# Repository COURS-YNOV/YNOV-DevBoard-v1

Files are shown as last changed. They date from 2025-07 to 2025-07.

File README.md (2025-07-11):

# 📟 Projet YNOV-DevBoard-v1 – Software & Hardware

Ce dépôt Git regroupe l'ensemble du projet **YNOV-DevBoard v1**, développé dans le cadre des cours de **Conception** & **Validation Électronique** en Master 1 à YNOV Bordeaux Campus.

Il contient deux dossiers complémentaires :

- Un contenant le **logiciel embarqué** permettant la réalisation des tests sur la carte.
- Un contenant le **projet hardware** complet de conception de la carte basée sur l’ESP32-PICO-D4.

---

## 🗂 Structure du dépôt

```
YNOV-DevBoard-v1/
│
├── software/   # Code source embarqué, tests unitaires, tests fonctionnels 
├── hardware/   # Schéma, PCB, documentation et contraintes de conception
└── README.md   # Ce fichier
```

---

## 🧪 Dossier `software/` – Logiciel embarqué de tests

Ce dossier contient le logiciel développé pour tester automatiquement les fonctionnalités de la carte **YNOV-DevBoard v1**.

📌 Fonctionnalités principales :
- Tests des capteurs (INA, TMP126, CTN)
- Tests des interfaces de communication (I2C, SPI, BLE)
- Tests des éléments HMI (LEDs, buzzer)
- Génération de **logs SPIFFS** pour suivre l’état des tests
- Contrôle local ou distant (via **BLE** avec l'application Python [`TheESP32Controller`](https://github.com/COURS-YNOV/TheESP32Controller))

🧪 Outils utilisés :
- PlatformIO + Framework Arduino
- Unity Framework pour les tests unitaires

📂 Pour plus de détails 👉 [Software/README.md](./Software/README.md)

---

## 📟 Dossier `hardware/` – Conception de la carte YNOV-DevBoard v1

Ce dossier contient tous les éléments nécessaires à la conception de la carte électronique :

📌 Spécifications :
- Microcontrôleur **ESP32-PICO-D4**
- Triple source d’alimentation (USB-C, BT, HT jusqu’à 36V)
- Capteurs de courant, tension, température (INA237, CTN, TMP126)
- Interfaces **BLE**, **MikroBus**, **Grove**
- Buzzer, LEDs, boutons BOOT et RESET

🔧 Fichiers fournis :
- Projet **Altium Designer** avec schématique & PCB vierges
- Bibliothèques de composants
- Contraintes de routage strictes (sans composants sur face bottom, pas d’angles droits, plan de masse obligatoire…)

📂 Pour plus de détails 👉 [Hardware/README.md](./Hardware/README.md)

---

## 🎓 Objectifs pédagogiques

- Concevoir une carte électronique respectant des contraintes industrielles.
- Développer un logiciel de test modulaire et automatisé.
- Apprendre les bonnes pratiques de tests embarqués (unitaires, fonctionnels, utilisation de logs ...).
- Travailler en synergie entre le hardware et le software.

---

## 📣 Remarques

- Ce projet est réalisé en **groupe**, mais la **notation est individuelle**.
- Des critères précis de notation sont définis dans chaque dossier (`software` et `hardware`).

---

## 🤝 Encadrement

Pour toute question ou besoin de support :
- Contactez vos **enseignants** :
  - [@Jordan CLÉMENT](https://github.com/Jordan18122000)
  - [@Dorian FOURNIER](https://github.com/DorianFournier)

- Utilisez les issues GitHub ou le canal de communication de votre groupe

---

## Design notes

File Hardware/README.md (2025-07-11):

# 📟 Projet Hardware – Carte de Développement YNOV-DevBoard-v1

## 📌 Objectifs

Vous devez concevoir une **carte électronique à base d’ESP32-PICO-D4** répondant aux exigences suivantes :

- **Alimentation multiple** avec priorité :
  - USB-C (5V)
  - Basse Tension (2.7V – 10V)
  - Haute Tension (jusqu’à 36V)
- **Capteurs**  :
   - Courant et tension via INA (communication en I2C)
   - Température via CTN (ADC)
   - Température via TMP126 (communication en SPI)
- **Interface homme-machine** :
  - Buzzer
  - LEDs
  - Boutons **Boot** et **Reset**
- **ICommunication sans fil** :
  - BLE
- **Compatibilité avec MikroBus et Grove**

### Étapes de réalisation

1. Analyse fonctionnelle du système
2. Sélection des composants
3. Réalisation de la schématique
4. Routage du PCB (taille max : **70mm x 50mm**)
5. Fournir :
   - Fichiers DRC sans erreurs
   - Fichiers de fabrication

Un projet Altium est fourni avec :
- Une schématique vide
- Un PCB vide
- Des bibliothèques de symboles et empreintes

---

## 📊 Notation

| Attendus | Points |
|---|---|
| **Schématique** | |
| Réalisation de la schématique | 7 |
| Câblage correct | 5 |
| Lisibilité de la schématique | 2 |
| **PCB** | |
| Réalisation du PCB | 5 |
| Respect des règles de routage/taille | 2 |
| DRC sans erreur | 2 |
| Fichiers de fabrication | 1 |
| **Rapport** | |
| Analyses fonctionnelles | 2 |
| Explication des blocs schématiques | 2 |
| Problèmes rencontrés + solutions | 2 |
| Suivi projet (jalons) | 2 |

⏳ **Deadline : 16 décembre 2024 à 17h00**  
📁 À rendre dans un `.zip` nommé `Equipe_NumeroX_Projet_rendu`, à **push sur GitHub** :  
👉 https://github.com/COURS-YNOV/Projet-YNOV-DevBoard-v1

---

## 📅 Planning recommandé

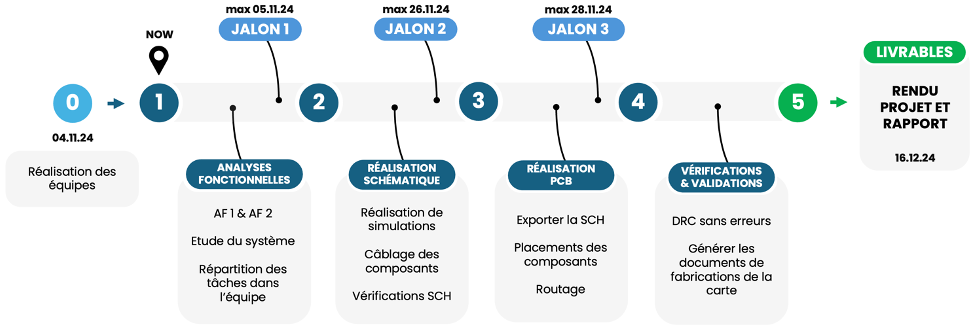
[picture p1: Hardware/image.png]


---

## 🔩 Composants principaux

| Fonction | Référence |
|---|---|
| Microcontrôleur  | ESP32-PICO-D4 |
| USB-UART | CP2104-F03-GM |
| Connecteur USB-C | USB4085-GF-A |
| Capteur courant  | INA237AIDGST |
| Divers | Résistances, Capa, LED, MikroBus, Grove, Antenne, boutons Boot/Reset, etc. |

---

## 🧩 Rappel schéma fonctionnel

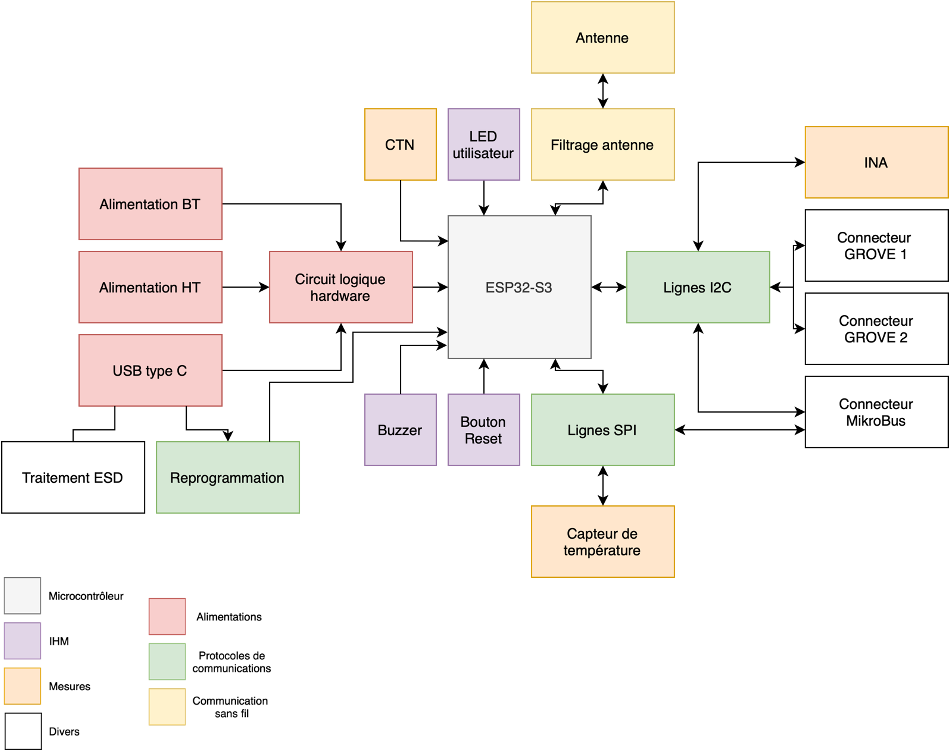
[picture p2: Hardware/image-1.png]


---

## 📐 Règles de conception imposées

### Général

- Schéma en **mils**
- PCB en **mm**
- Titre, révision et nom du dessinateur sur la schématique

### Schématique

- Les **paires différentielles** doivent apparaître

### Routage

- ❌ **Pas d’angles droits**
- ✅ Connexions au **centre des pads**
- ✅ Éviter les angles aigus/soudures complexes
- ✅ Plan de masse **obligatoire**
- ❌ Aucun composant sur la face **Bottom**
- **Vias** :
  - Pad : 0.85 mm
  - Trou : 0.35 mm
- **Sérigraphie** : largeur min. 0.15 mm
- **Impédance ligne de reprogrammation** : 50 Ohms
- **Plan masse/puissance** adapté à l'antenne BLE
- Vias d’assemblage selon besoins (Top layer)

---

## 🔗 Liens utiles

| Description | Lien |
|---|---|
| Raccourcis Altium | [click](https://www.altium.com/documentation/altium-designer/shortcut-keys#shortcut-listings) |
| Guide de routage | [click](https://www.rowsum.com/fr/31-conseils-de-routage-des-circuits-imprimes/) |
| Calculateur de résistance | [click](https://www.digikey.fr/en/resources/conversion-calculators/conversion-calculator-led-series-resistor) |

---

## 💬 Remarque

Ce projet est **en groupe**, mais la **notation est individuelle**.

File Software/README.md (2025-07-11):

# 🧪 Logiciel de Vérification et Validation Électronique – M1 Ynov

Ce dépôt contient le logiciel embarqué utilisé dans le cadre du cours de **Vérification et Validation Électronique** destiné aux étudiants de **Master 1**.  
Le logiciel est développé avec **PlatformIO** et le **framework Arduino**, et doit être déployé sur une carte **ESP32-PICO-D4**.

Ce projet vise à fournir une solution d'automatisation pour effectuer des tests sur des cartes électroniques, permettant ainsi de valider leur bon fonctionnement.

---

## 🎯 Objectif

Le but de ce projet est de permettre aux étudiants de réaliser des **tests automatisés** sur les cartes électroniques **YNOV-DevBoard v1**. Ces tests peuvent être exécutés localement sur la carte ou à distance via l'application Python **TheESP32Controller**, qui interagit avec la carte grâce à la bibliothèque [`bleak`](https://github.com/hbldh/bleak) pour la gestion de la communication Bluetooth Low Energy (BLE).

Les tests automatisés couvrent diverses fonctionnalités matérielles de la carte et permettent de vérifier leur bon fonctionnement avant leur mise en production.

---

## ⚙️ Technologies utilisées

- **ESP32-PICO-D4** : Microcontrôleur présent sur la carte YNOV-DevBoard-v1.
- **PlatformIO** : IDE utilisé pour gérer la compilation, l'upload, et les tests unitaires.
- **Arduino Framework** : Framework de programmation utilisé pour simplifier le développement embarqué.
- **BLE (Bluetooth Low Energy)** : Technologie de communication sans fil pour l'interaction avec l'application Python [`TheESP32Controller`](https://github.com/COURS-YNOV/TheESP32Controller).
- **Bleak** : Bibliothèque utiliséé pour gérer la communication BLE entre la carte et l'application Python "TheESP32Controller".
- **Unity Framework** : Framework de tests unitaires pour vérifier la validité des composants logiciels embarqués.

---

## 🧩 Fonctionnalités & Tests Implémentés

Ce software permet d'exécuter les tests suivants sur la carte **YNOV-DevBoard v1** :

### Tests des périphériques
- 🔴 **Test des LEDs** : Vérifie la bonne activation des LEDs de la carte.
- 🔊 **Test du Buzzer** : Vérifie que le buzzer fonctionne correctement en émettant des sons.
- 🌡️ **Test du capteur de température** : Teste le capteur TMP126 pour s'assurer qu'il peut mesurer la température de manière précise.
- 📉 **Test des CTN (Thermistances)** : Vérifie le bon fonctionnement des capteurs de température thermistances.
- ⚡ **Test du capteur INA** : Vérifie le bon fonctionnement du capteur INA237 pour mesurer la consommation de courant et la tension.
 
### Tests de communication
- 🔗 **Test de la communication I2C** : Vérifie que la communication I2C fonctionne correctement entre l'ESP32 et les périphériques connectés.
- 🔀 **Test de la communication SPI** : Vérifie la communication SPI entre l'ESP32 et les périphériques compatibles SPI (capteur de température).

### Tests de connectivité
- 📡 **Test BLE** : Vérifie la communication Bluetooth Low Energy (BLE) entre l'ESP32 et l'application Python **TheESP32Controller**.

### Tests divers
- **Test PWM** : Vérifie le bon fonctionnement des signaux PWM générés par la carte.
- **Test Free Text** :  Vérifie la bonne reception/envoie de données personnalisées via BLE.
- **Test acknowledge ESP32** : Teste la capacité de la carte ESP32 à répondre à des requêtes de confirmation via BLE.
- 📝 **Test d'écriture/lecture de fichier en RAM** : Vérifie la capacité de l'ESP32 à lire et écrire dans la mémoire RAM pendant l'exécution d'un test.
- 📑 **Test de génération et vérification de logs SPIFFS** : Vérifie l'enregistrement des résultats des tests dans un fichier `log.txt` stocké dans la mémoire SPIFFS de l'ESP32.

---

## ⚙️ Architecture

### Structure du projet
Le projet est organisé en plusieurs dossiers pour une gestion claire et structurée du code source :

- **`src/`** : Contient le code principal de l'application embarquée.
- **`lib/`** : Contient les drivers développés pour la configuration et l'execution des tests.
- **`include/`** : Contient les fichiers constantes et de configurations utilisés dans le projet.
- **`tests/`** : Contient les tests unitaires, organisés par fonctionnalité, pour vérifier le bon fonctionnement du code embarqué.

### 🚀 Téléverser le fichier sur la carte (SPIFFS)

Avant d'exécuter les tests, il est nécessaire de téléverser le fichier `log.txt` dans la mémoire flash SPIFFS de l'ESP32 pour enregistrer les résultats des tests.

Utilisez la commande suivante pour télécharger ce fichier sur l'ESP32 :

```bash
pio run --target uploadfs
```

# 🧪 Tests unitaires embarqués

Des tests unitaires sont inclus dans ce dépôt et peuvent être exécutés à l’aide du framework Unity.

Ces tests permettent de vérifier le bon fonctionnement des différentes parties du code source de manière isolée, garantissant ainsi la fiabilité du firmware.

## ▶️ Lancer les tests unitaires

Pour lancer les tests unitaires sur la plateforme ESP32, utilisez la commande suivante dans PlatformIO :

```bash
pio test -e esp32
```

Cette commande exécute tous les tests définis dans le répertoire `tests/` et génère un rapport détaillant les résultats.

## 📑 Test des logs SPIFFS

Les résultats des tests sont enregistrés dans un fichier `log.txt` situé dans la mémoire flash SPIFFS de l'ESP32. Ce fichier est utilisé pour stocker les résultats de chaque test exécuté. Vous pouvez vérifier son contenu en vous connectant à la carte et en lisant le fichier SPIFFS pour vous assurer que les logs sont correctement enregistrés.

Pour tester cela, vous devez effectuer les étapes suivantes :

1. Exécutez les tests.
2. Vérifiez le fichier `log.txt` dans SPIFFS pour vous assurer que toutes les informations sont correctement enregistrées.
3. Consultez le contenu du fichier avec un logiciel de lecture (par exemple, via un terminal ou en utilisant l'application Python).

## 🧑‍💻 Utilisation du logiciel

### 1. Préparer l'environnement

Clonez le dépôt :

```bash
git clone https://votre-url-de-dépôt.git
```

Installez PlatformIO :

Si vous ne l'avez pas déjà fait, installez PlatformIO en suivant la documentation officielle : PlatformIO.

Installez les dépendances :

Une fois le dépôt cloné, installez les bibliothèques nécessaires à l'aide de la commande suivante :

```bash
pio lib install
```

### 2. Télécharger le firmware sur l'ESP32

Téléversez le firmware sur la carte ESP32 avec la commande suivante :

```bash
pio run --target upload
```

### 3. Exécuter les tests

Les tests peuvent être exécutés de deux manières :

- **Test local** : Exécutez tous les tests unitaires directement sur l'ESP32 :

```bash
pio test -e esp32
```

- **Test via Bluetooth BLE (à distance)** : Utilisez l'application TheESP32Controller en Python pour interagir avec l'ESP32 via BLE et lancer les tests à distance.

### 4. Consulter les logs

Les résultats des tests sont enregistrés dans le fichier `log.txt` dans la mémoire SPIFFS de l'ESP32. Vous pouvez consulter ce fichier pour vérifier l'état de chaque test exécuté.

## 📝 Notation

Voici un tableau de notation qui peut être utilisé pour évaluer la qualité et l'exhaustivité des tests effectués.

| Critère | Description | Points  |
|---|---|---|
| Tests des LEDs | Vérification correcte de l'activation des LEDs. | |
| Test du Buzzer | Vérification correcte du son émis par le buzzer. | |
| Test du capteur TMP126 | Précision des mesures de température. | |
| Tests de communication (I2C, SPI) | Fonctionnalité des communications I2C et SPI. | |
| Test BLE | Bon fonctionnement de la communication BLE. | |
| Tests divers (PWM, Free Text, etc.) | Vérification des autres tests variés. | |
| Test des logs SPIFFS | Enregistrement correct des résultats dans `log.txt`.  | |
| Ajout de tests unitaires | Création de tests unitaires dans le projet.  | |
| Ajout de GitHub Action | Utilisation des GitHub Actions.  | |

## 📋 TODO

Voici une liste des tâches restantes ou des fonctionnalités à ajouter pour améliorer ce projet :

- Tests de la communication avec la ROM externe
- Tests de performance : Implémenter des tests pour mesurer la consommation de mémoire et la performance de l'ESP32 pendant l'exécution des tests.

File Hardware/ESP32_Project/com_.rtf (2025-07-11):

https://www.mouser.fr/datasheet/2/268/MCHP_S_A0010728890_1-2521060.pdf

MCP73831T-3ACI/OT
579-MCP73831T-3ACIOT

https://www.mouser.fr/ProductDetail/Microchip-Technology/MCP73831T-3ACI-OT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

—————————————————————————————————

https://www.digikey.fr/en/products/detail/CP2104-F03-GM/336-2008-5-ND/2486177?curr=usd
CP2104-F03-GM

—————————————————————————————————

https://www.mouser.fr/ProductDetail/AP-Memory/APS1604M-3SQR-SN?qs=IS%252B4QmGtzzpULD7HVv5Qww%3D%3D

PSRAM

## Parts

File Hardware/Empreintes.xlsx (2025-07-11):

NAME | Description | Designator | Qty | MP | Manufacturer | Footprint | V | Check
114020164 | Seeed Studio Accessories Grove Female Header - SMD-4P-2.0mm-90D-20Pcs | J202, J203 | 2 | KO | KO | 114020164 | NA | OK
598-8610-207F | Standard LEDs - SMD Red/Green WC 80/50mcd 645/570nm | D600 | 1 | KO | KO | 5988610207F | NA
0.1uF | Capa | C101, C104, C108, C300, C500 | 5 | KO | KO | CAPA_0603 | NA | OK
0.6pF | Capa | C600 | 1 | KO | KO | CAPA_0603 | NA | OK
0.9pF | Capa | C601 | 1 | KO | KO | CAPA_0603 | NA | OK
1nF | Capa | C105 | 1 | KO | KO | CAPA_0603 | NA | OK
1.0pF | Capa | C602 | 1 | KO | KO | CAPA_0603 | NA | OK
1uF | Capa | C100, C102, C103, C107, C303, C304 | 6 | KO | KO | CAPA_0603 | NA | OK
2.2uF | Capa | C302 | 1 | KO | KO | CAPA_0603 | NA | OK
4.7uF | Capa | C106 | 1 | KO | KO | CAPA_0603 | NA | OK
5mF | Capa | C400 | 1 | KO | KO | CAPA_0603 | NA | OK
10uF | Capa | C301 | 1 | KO | KO | CAPA_0603 | NA | OK
22uF | Capa | C305 | 1 | KO | KO | CAPA_0603 | NA | OK
47nF | Capa | C603, C604, C605, C606 | 4 | KO | KO | CAPA_0603 | NA | OK
100nF | Capa | C200, C401, C402, C403, C404, C405, C406, C407, C501, C502 | 10 | KO | KO | CAPA_0603 | NA | OK
825433-8 | Headers & Wire Housings 8P double for connection mikrobus | J200 | 1 | KO | KO | Connect-Mikrobus | NA
4.7uH | Self | L300 | 1 | KO | KO | LQPC1005X06N | NA
10uF | Capa | L301 | 1 | KO | KO | LQPC1005X06N | NA
NCP167BMX330TBG | Régulateurs de tension LDO LDO 700 MA ULTRA-LOW NOISE 3.3V | U300 | 1 | KO | KO | NCP167BMX330TBG | NA
CP2104-F03-GM | USB Bridge, USB to UART USB 2.0 UART Interface 24-QFN (4x4) | U101 | 1 | KO | KO | PQFN50P400X400X80_HS-25N | NA
ESP32-PICO-D4 | Système RF sur puce - SoC SIP module ESP32 with 4MByte Flash, Dual Core MCU, Wi-Fi & Bluetooth Combo, LGA48-pin, 7*7mm | U100 | 1 | KO | KO | PQFN50P700X700X104_HS-49N | NA
1K | Résistance | R600, R603 | 2 | KO | KO | RES_0603 | NA | OK
2K | Résistance | R502, R503 | 2 | KO | KO | RES_0603 | NA | OK
4.7K | Résistance | R100 | 1 | KO | KO | RES_0603 | NA | OK
5K1 | Résistance | R200, R201 | 2 | KO | KO | RES_0603 | NA | OK
5.1K | Résistance | R605, R607 | 2 | KO | KO | RES_0603 | NA | OK
10K | Résistance | R101, R102, R104, R401, R403, R405, R500, R501, R604, R606 | 10 | KO | KO | RES_0603 | NA | OK
10R | Résistance | R504, R505 | 2 | KO | KO | RES_0603 | NA | OK
22.1K | Résistance | R301 | 1 | KO | KO | RES_0603 | NA | OK
51K | Résistance | R300 | 1 | KO | KO | RES_0603 | NA | OK
100k | Résistance | R302 | 1 | KO | KO | RES_0603 | NA | OK
100K | Résistance | R400, R402, R404 | 3 | KO | KO | RES_0603 | NA | OK
150R | Résistance | R601, R602 | 2 | KO | KO | RES_0603 | NA | OK
510R | Résistance | R103 | 1 | KO | KO | RES_0603 | NA | OK
PSR400ITQFF0L50 | ROHM - PSR400ITQFF0L50 - SMD Current Sense Resistor, 500 ohm, PSR Series, 3921 [1052 Metric], 4 W, +/- 1%, Metal Strip | X500 | 1 | KO | KO | RESC10052X200N | NA
NB12K00103JBB | NTC SMD Thermistor, NB12K, 10K, 5% AVX 10k 0805 Protection NTC Thermistor, 5s, 2 x 1.25 x 1.3mm | B600, B601 | 2 | KO | KO | RESC2212X50N | NA
SD103AWS-7-F | Diode Array 3 Independent Schottky 40V 175mA Surface Mount 6-TSSOP, SC-88, SOT-363 | DARR700, DARR701, DARR702 | 3 | KO | KO | SD103AWS-7-F | NA
IS66WVS1M8BLL-104NLI | SRAM 8Mb, SerialRAM, 2.7V-3.6V, 104MHz, 8 pin SOIC 150 mil, RoHS | U102 | 1 | KO | KO | SOIC127P600X175-8N | NA
INA237AIDGST | Current Sense Amplifiers 85-V, 16-bit, I2C output current/voltage/power monitor with alert 10-VSSOP -40 to 125 | B500 | 1 | KO | KO | SOP50P490X110-10N | NA
TPS62056DGSG4 | TEXAS INSTRUMENTS - TPS62056DGSG4 - Synchronous Buck (Step Down) Switching Regulator, Fixed, 2.7V-10Vin, 3.3V/0.8A out, 850kHz, VSSOP-10 | B301 | 1 | KO | KO | SOP50P490X110-10N | NA
74VHC05FT | Logic Gates CMOS LOGIC IC INVERTER | B401 | 1 | KO | KO | SOP65P640X120-14N | NA
824011 | TVS Diode Array WE-TVS, High Speed Series - Low capazity - No leakage current - Low clamping voltage - high ESD voltage protection -- USB 1.0 - 2.0 | D200 | 1 | KO | KO | SOT23-5 | NA
MC74VHC1GT32DFT1G | Single 2-Input OR Gate, TTL Level | B400, B402, B403 | 3 | KO | KO | SOT65P210X110-5N | NA
TMP126DCKR | Board Mount Temperature Sensors +/-0.25 C SPI temperature sensor with 175 C operation, CRC and slew-rate alert | B501 | 1 | KO | KO | SOT65P210X110-6N | NA
FDV304P | ON SEMICONDUCTOR - FDV304P - Power MOSFET, P Channel, 25 V, 460 mA, 1.22 ohm, SOT-23, Surface Mount | Q400, Q401, Q402 | 3 | KO | KO | SOT95P251X112-3N | NA
LMR50410Y3FQDBVRQ1 | Régulateurs de tension de commutation Automotive qualified SIMPLE SWITCHER 4-V to 36-V, 1-A synchronous step-down converter 6-SOT-23 -40 to 150 | B300 | 1 | KO | KO | SOT95P280X145-6N | NA
2N7002KT1G | MOSFET N-Ch 60V 380mA Small Signal SOT23 ON Semiconductor 2N7002KT1G N-channel MOSFET Transistor, 380 mA, 60 V, 3-Pin SOT-23 | Q600 | 1 | KO | KO | SOT96P237X111-3N | NA
PKLCS1212E40A1-R1 | Buzzers Transducer, Externally Driven Piezo 1.5V 2kHz 70dB @ 1.5V, 10cm Surface Mount Solder Pads | LS600 | 1 | PKLCS1212E40A1-R1 | KO | SPKR_PKLCS1212E40A1-R1 | NA
SS8050-G | Bipolar Transistors - BJT NPN TRANSISTOR 1.5A 40V | Q100, Q101 | 2 | KO | KO | SS8050-G | NA
FSMSM | FSMSM Push Button Switch, 50 mA, -35 to 85 degC, 2-Pin SMD, RoHS, Bulk | SW200, SW201 | 2 | KO | TE Connectivity | TECO-FSMSM-2_V | 24V
Connecteur USB | Connecteurs USB USB Type C, 2.0, Rec, TH , G/F, RA , Top Mnt, T & R | J201 | 1 | KO | KO | USB4085-GF-A | NA
Filtre en mode commun | Bobines / filtres en mode commun WE-CNSW 1206 370mA 90Ohm 100MHz AECQ200 | L200 | 1 | KO | KO | WE-CNSW-1206 | NA
NN03-320 | Dual port antenna booster for GNSS, Bluetooth, 5G and UWB (1561 - 1606MHz, 2400 - 2500MHz, 3400 - 3800MHz, 3100 - 4800MHz and 6000 - 10600 MHz), signal booster | E600 | 1 | KO | KO | XCVR_NN03-320 | NA

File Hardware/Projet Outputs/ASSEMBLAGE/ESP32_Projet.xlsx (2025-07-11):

Comment | Description | Designator | Footprint | LibRef | Quantity | Lien
LMR50410Y3FQDBVRQ1 | Régulateurs de tension de commutation Automotive qualified SIMPLE SWITCHER 4-V to 36-V, 1-A synchronous step-down converter 6-SOT-23 -40 to 150 | B300 | SOT95P280X145-6N | LMR50410Y3FQDBVRQ1 | 1 | https://www.mouser.fr/ProductDetail/Texas-Instruments/LMR50410Y3FQDBVRQ1?qs=81r%252BiQLm7BTaIXwCgdOuiA%3D%3D
TPS62056DGSG4 | TEXAS INSTRUMENTS - TPS62056DGSG4 - Synchronous Buck (Step Down) Switching Regulator, Fixed, 2.7V-10Vin, 3.3V/0.8A out, 850kHz, VSSOP-10 | B301 | SOP50P490X110-10N | TPS62056DGSG4 | 1 | https://www.mouser.fr/ProductDetail/Texas-Instruments/TPS62056DGSG4?qs=Gse6rAGbi7%2FzZ8O9jVxOPw%3D%3D
MC74VHC1GT32DFT1G | Single 2-Input OR Gate, TTL Level | B400, B402, B403 | SOT65P210X110-5N | MC74VHC1GT32DFT1G | 3 | https://www.mouser.fr/ProductDetail/onsemi/MC74VHC1GT32DFT1G?qs=3Rah4i%252BhyCF0HPzZACsD%252BA%3D%3D
74VHC05FT | Logic Gates CMOS LOGIC IC INVERTER | B401 | SOP65P640X120-14N | 74VHC05FT | 1 | https://www.mouser.fr/ProductDetail/Toshiba/74VHC05FT?qs=vPP9GyyTAo2HsJPKD%2FomJQ%3D%3D
INA237AIDGST | Current Sense Amplifiers 85-V, 16-bit, I2C output current/voltage/power monitor with alert 10-VSSOP -40 to 125 | B500 | SOP50P490X110-10N | INA237AIDGST | 1 | https://www.mouser.fr/ProductDetail/Texas-Instruments/INA237AIDGST?qs=CiayqK2gdcJbJJ4nef%252BF8w%3D%3D
TMP126DCKR | Board Mount Temperature Sensors +/-0.25 C SPI temperature sensor with 175 C operation, CRC and slew-rate alert | B501 | SOT65P210X110-6N | TMP126DCKR | 1 | https://www.mouser.fr/ProductDetail/Texas-Instruments/TMP126DCKR?qs=4ASt3YYao0X%252BRzld6Zs7yw%3D%3D
NB12K00103JBB | NTC SMD Thermistor, NB12K, 10K, 5% AVX 10k 0805 Protection NTC Thermistor, 5s, 2 x 1.25 x 1.3mm | B600, B601 | RESC2212X50N | NB12K00103JBB | 2 | https://www.mouser.fr/ProductDetail/KYOCERA-AVX/NB12K00103JBB?qs=4%252B6%252BTdINQeDPvI%252BQUQjJ3Q%3D%3D
1uF |  | C100, C102, C103, C107, C303, C304 | CAPA_0603 | Capacitor | 6 | https://www.mouser.fr/ProductDetail/KYOCERA-AVX/06035C105MAT2A
0.1uF |  | C101, C104, C108, C300, C500 | CAPA_0603 | Capacitor | 5 | https://www.mouser.fr/ProductDetail/TAIYO-YUDEN/MAJCU168BB7104KTEA01?qs=ZcfC38r4PovJ4zMRJqa98Q%3D%3D
1nF |  | C105 | CAPA_0603 | Capacitor | 1 | https://www.mouser.fr/ProductDetail/Murata-Electronics/GRM188R72E102KW07D?qs=0EDxBdtd5TTqBbAL3ZuZjw%3D%3D
4.7uF |  | C106 | CAPA_0603 | Capacitor | 1 | https://www.mouser.fr/ProductDetail/TAIYO-YUDEN/MCASJ168BD7475KTCA01?qs=jcD%2FCkGBYeN5KiSgETBBHQ%3D%3D
100nF |  | C200, C401, C402, C403, C404, C405, C406, C407, C501, C502 | CAPA_0603 | Capacitor | 10 | https://www.mouser.fr/ProductDetail/TAIYO-YUDEN/MAJCU168BB7104KTEA01?qs=ZcfC38r4PovJ4zMRJqa98Q%3D%3D
10uF |  | C301 | CAPA_0603 | Capacitor | 1 | https://www.mouser.fr/ProductDetail/Murata-Electronics/ZRB18AR6YA106ME01L?qs=HoCaDK9Nz5eXg14MFgF2fw%3D%3D
2.2uF |  | C302 | CAPA_0603 | Capacitor | 1 | https://www.mouser.fr/ProductDetail/Samsung-Electro-Mechanics/CL10Y225KA8NRWC?qs=i8QVZAFTkqS9y8P4YmSrrQ%3D%3D
22uF |  | C305 | CAPA_0603 | Capacitor | 1 | https://www.mouser.fr/ProductDetail/KYOCERA-AVX/CM105X5R226M16AT?qs=MyNHzdoqoQKX6cMyStcF%2FA%3D%3D
5mF |  | C400 | CAPA_0603 | Capacitor | 1 | NOT USE
0.6pF |  | C600 | CAPA_0603 | Capacitor | 1 | https://www.mouser.fr/ProductDetail/Murata-Electronics/GRM1885C1HR60WA01D?qs=4W3PNmGdEWEpP9oqudN2kA%3D%3D
0.9pF |  | C601 | CAPA_0603 | Capacitor | 1 | https://www.mouser.fr/ProductDetail/Vishay-Vitramon/VJ0603D0R9VXCQJHT?qs=81r%252BiQLm7BQRNGxx7uvesg%3D%3D
1.0pF |  | C602 | CAPA_0603 | Capacitor | 1 | https://www.mouser.fr/ProductDetail/Vishay-Vitramon/VJ0603D1R0BXPAJ?qs=f%252BL2SN1Gfcun1bEHWO%2FG%252Bw%3D%3D
47nF |  | C603, C604, C605, C606 | CAPA_0603 | Capacitor | 4 | https://www.mouser.fr/ProductDetail/KYOCERA-AVX/KAM15AR71H473KM?qs=Jm2GQyTW%2Fbirhk%2FTN5CLyw%3D%3D
824011 | TVS Diode Array WE-TVS, High Speed Series - Low capazity - No leakage current - Low clamping voltage - high ESD voltage protection -- USB 1.0 - 2.0 | D200 | SOT23-5 | 824011 | 1 | https://www.mouser.fr/ProductDetail/Wurth-Elektronik/824011?qs=Wn16VcyqZWrHR48Vn%2FB8%252Bg%3D%3D
598-8610-207F | Standard LEDs - SMD Red/Green WC 80/50mcd 645/570nm | D600 | 5988610207F | 598-8610-207F | 1 | https://www.mouser.fr/ProductDetail/Dialight/598-8610-207F?qs=7JStj%2FjQ2SFuCjosqwklHQ%3D%3D
SD103AWS-7-F | Diode Array 3 Independent Schottky 40V 175mA Surface Mount 6-TSSOP, SC-88, SOT-363 | DARR700, DARR701, DARR702 | SD103AWS-7-F | SD103AWS-7-F | 3 | https://www.mouser.fr/ProductDetail/Diodes-Incorporated/SD103AWS-7-F?qs=yDXQ%2Fb33kn1tCz%252Bb09bzhg%3D%3D
NN03-320 | Dual port antenna booster for GNSS, Bluetooth, 5G and UWB (1561 - 1606MHz, 2400 - 2500MHz, 3400 - 3800MHz, 3100 - 4800MHz and 6000 - 10600 MHz), signal booster | E600 | XCVR_NN03-320 | NN03-320 | 1 | https://www.mouser.fr/ProductDetail/Ignion/NN03-320?qs=OTrKUuiFdkbF20ahZYIa2w%3D%3D
825433-8 | Headers & Wire Housings 8P double for connection mikrobus | J200 | Connect-Mikrobus | Connect-Mikrobus | 1
Connecteur USB | Connecteurs USB USB Type C, 2.0, Rec, TH , G/F, RA , Top Mnt, T & R | J201 | USB4085-GF-A | USB4085-GF-A | 1 | https://www.mouser.fr/ProductDetail/GCT/USB4085-GF-A?qs=KUoIvG%2F9Ilba1bQOahfWjw%3D%3D
114020164 | Seeed Studio Accessories Grove Female Header - SMD-4P-2.0mm-90D-20Pcs | J202, J203 | 114020164 | 114020164 | 2 | https://www.mouser.fr/ProductDetail/Seeed-Studio/114020164?qs=7MVldsJ5Uayw%2FOfizq4F8w%3D%3D
3.3uH, 3.5A | WE-LHMI SMT Power Inductor, size 4020, 3.3uH, 3.5A, 76mOhm | L1 | WE-LHMI_4020 | 74437324033 | 1 | https://www.mouser.fr/ProductDetail/Wurth-Elektronik/74437324033?qs=cFlH0mFHHFqAbArPxGVEdA%3D%3D
10uH, 2A | WE-PD SMT Power Inductor, size 7345, 10uH, 2A, 49mOhm | L2 | WE-PD_7345 | 74477710 | 1 | https://www.mouser.fr/ProductDetail/Wurth-Elektronik/74477710?qs=E%2F%2FhvbtCqpNuU6Mc9NsODA%3D%3D
Filtre en mode commun | Bobines / filtres en mode commun WE-CNSW 1206 370mA 90Ohm 100MHz AECQ200 | L200 | WE-CNSW-1206 | 744232090 | 1 | https://www.mouser.fr/ProductDetail/Wurth-Elektronik/744232090?qs=PGXP4M47uW6L5fAiLO6yTw%3D%3D
PKLCS1212E40A1-R1 | Buzzers Transducer, Externally Driven Piezo 1.5V 2kHz 70dB @ 1.5V, 10cm Surface Mount Solder Pads | LS1 | SPKR_PKLCS1212E40A1-R1 | PKLCS1212E40A1-R1 | 1 | https://www.mouser.fr/ProductDetail/Murata-Electronics/PKLCS1212E40A1-R1?qs=5UjbJB5E4AfH47ysIIPj%2FQ%3D%3D
SS8050-G | Bipolar Transistors - BJT NPN TRANSISTOR 1.5A 40V | Q100, Q101 | SS8050-G | SS8050-G | 2 | https://www.mouser.fr/ProductDetail/Comchip-Technology/SS8050-G?qs=LLUE9lz1YbcHg%252BWLMAtcrQ%3D%3D
FDV304P | ON SEMICONDUCTOR - FDV304P - Power MOSFET, P Channel, 25 V, 460 mA, 1.22 ohm, SOT-23, Surface Mount | Q400, Q401, Q402 | SOT95P251X112-3N | FDV304P | 3 | https://www.mouser.fr/ProductDetail/onsemi-Fairchild/FDV304P?qs=FOlmdCx%252BAA1BAlCQZu888w%3D%3D
2N7002KT1G | MOSFET N-Ch 60V 380mA Small Signal SOT23 ON Semiconductor 2N7002KT1G N-channel MOSFET Transistor, 380 mA, 60 V, 3-Pin SOT-23 | Q600 | SOT96P237X111-3N | 2N7002KT1G | 1 | https://www.mouser.fr/ProductDetail/onsemi/2N7002KT1G?qs=Jh7l0IbPjifUiTytu%252BGGDQ%3D%3D
4.7K |  | R100 | RES_0603 | Resistor | 1 | https://www.mouser.fr/ProductDetail/KOA-Speer/RS73G1JRTTD4701F
10K |  | R101, R102, R104, R401, R403, R405, R500, R501, R604, R606 | RES_0603 | Resistor | 10 | https://www.mouser.fr/ProductDetail/SEI-Stackpole/RNCE0603BTE10K0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
510R |  | R103 | RES_0603 | Resistor | 1 | https://www.mouser.fr/ProductDetail/ROHM-Semiconductor/KTR03EZPF5100
5K1 |  | R200, R201 | RES_0603 | Resistor | 2 | https://www.mouser.fr/ProductDetail/Vishay/CRCW06035K10FKEC
51K |  | R300 | RES_0603 | Resistor | 1 | https://www.mouser.fr/ProductDetail/Panasonic/ERA-3ARB513V?qs=sGAEpiMZZMtlubZbdhIBIJiMSTY83nT4HuGl7M9CVy4%3D
22.1K |  | R301 | RES_0603 | Resistor | 1 | https://www.mouser.fr/ProductDetail/TE-Connectivity-Holsworthy/RA73F1J22K1BTDF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
100k |  | R302, R400, R402, R404 | RES_0603 | Resistor | 4 | https://www.mouser.fr/ProductDetail/Vishay/CRCW0603100KFKEE
2K |  | R502, R503 | RES_0603 | Resistor | 2 | https://www.mouser.fr/ProductDetail/SEI-Stackpole/RNCE0603BTE2K00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
10R |  | R504, R505 | RES_0603 | Resistor | 2 | https://www.mouser.fr/ProductDetail/SEI-Stackpole/RNCE0603BTE10R0
1K |  | R600, R603 | RES_0603 | Resistor | 2 | https://www.mouser.fr/ProductDetail/SEI-Stackpole/RNCE0603BTE1K00
150R |  | R601, R602 | RES_0603 | Resistor | 2 | https://www.mouser.fr/ProductDetail/SEI-Stackpole/RNCE0603BTE150R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
5.1K |  | R605, R607 | RES_0603 | Resistor | 2 | https://www.mouser.fr/ProductDetail/Vishay/CRCW06035K10FKEC
FSMSM | FSMSM Push Button Switch, 50 mA, -35 to 85 degC, 2-Pin SMD, RoHS, Bulk | SW200, SW201 | TECO-FSMSM-2_V | CMP-2000-07511-1 | 2 | https://www.mouser.fr/ProductDetail/TE-Connectivity-Alcoswitch/FSMSM?qs=UhRTNahLC3yPLf3YjzjKAA%3D%3D
ESP32-PICO-D4 | Système RF sur puce - SoC SIP module ESP32 with 4MByte Flash, Dual Core MCU, Wi-Fi & Bluetooth Combo, LGA48-pin, 7*7mm | U100 | PQFN50P700X700X104_HS-49N | ESP32 | 1 | https://www.mouser.fr/ProductDetail/Espressif-Systems/ESP32-PICO-D4?qs=MLItCLRbWsw7MJlbN3HfdA%3D%3D
CP2104-F03-GM | USB Bridge, USB to UART USB 2.0 UART Interface 24-QFN (4x4) | U101 | PQFN50P400X400X80_HS-25N | USBBridge | 1 | https://www.mouser.fr/ProductDetail/Silicon-Labs/CP2104-F03-GM?qs=j12q4iUN960zrcKDk%2FjKbw%3D%3D
IS66WVS1M8BLL-104NLI | SRAM 8Mb, SerialRAM, 2.7V-3.6V, 104MHz, 8 pin SOIC 150 mil, RoHS | U102 | SOIC127P600X175-8N | SRAM | 1 | https://www.mouser.fr/ProductDetail/ISSI/IS66WVS1M8BLL-104NLI?qs=doiCPypUmgGxZh5L3cgVoQ%3D%3D
NCP167BMX330TBG | Régulateurs de tension LDO LDO 700 MA ULTRA-LOW NOISE 3.3V | U300 | NCP167BMX330TBG | NCP167BMX330TBG | 1 | https://www.mouser.fr/ProductDetail/onsemi/NCP167BMX330TBG?qs=MLItCLRbWsxdhppZpZlnwg%3D%3D
PSR400ITQFF0L50 | ROHM - PSR400ITQFF0L50 - SMD Current Sense Resistor, 500 ohm, PSR Series, 3921 [1052 Metric], 4 W, +/- 1%, Metal Strip | X500 | RESC10052X200N | PSR400ITQFF0L50 | 1 | https://www.mouser.fr/ProductDetail/ROHM-Semiconductor/PSR400ITQFF0L50?qs=493kPxzlxfLaT1w5Mo%252BtHg%3D%3D

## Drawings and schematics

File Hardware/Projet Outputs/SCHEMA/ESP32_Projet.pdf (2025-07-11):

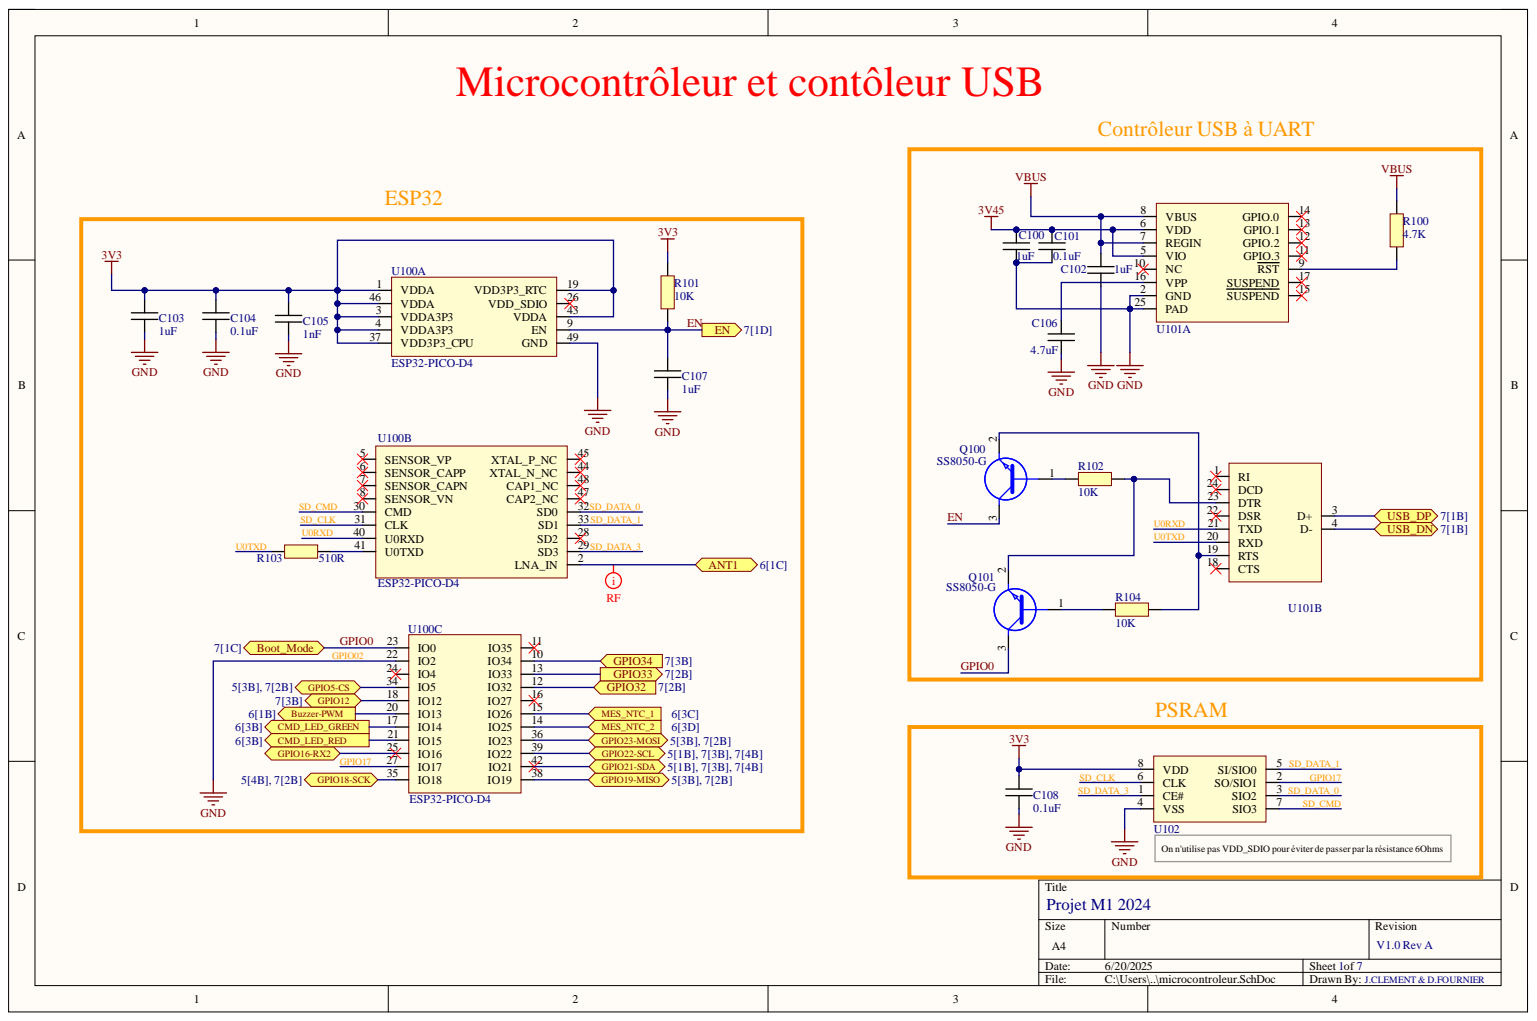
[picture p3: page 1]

4 | 6 | V D D A V D D _SD I O V D D A 3 P 3 V D D A V D D A 3 P 3 E N V D D 3P3 _ C PU G N D | 2 6 3

2 3 5[3B], 7[2B] GP IO5-C S 1 7[3 B ] GP IO1 2 2 6[1 B ] Buz z e r -PWM 1 6[3 B ] C MD_L ED_GR EEN 2 6[3 B ] C MD_L ED_R ED 2 GP IO16-R X 2 | 4 | 13 2 IO33

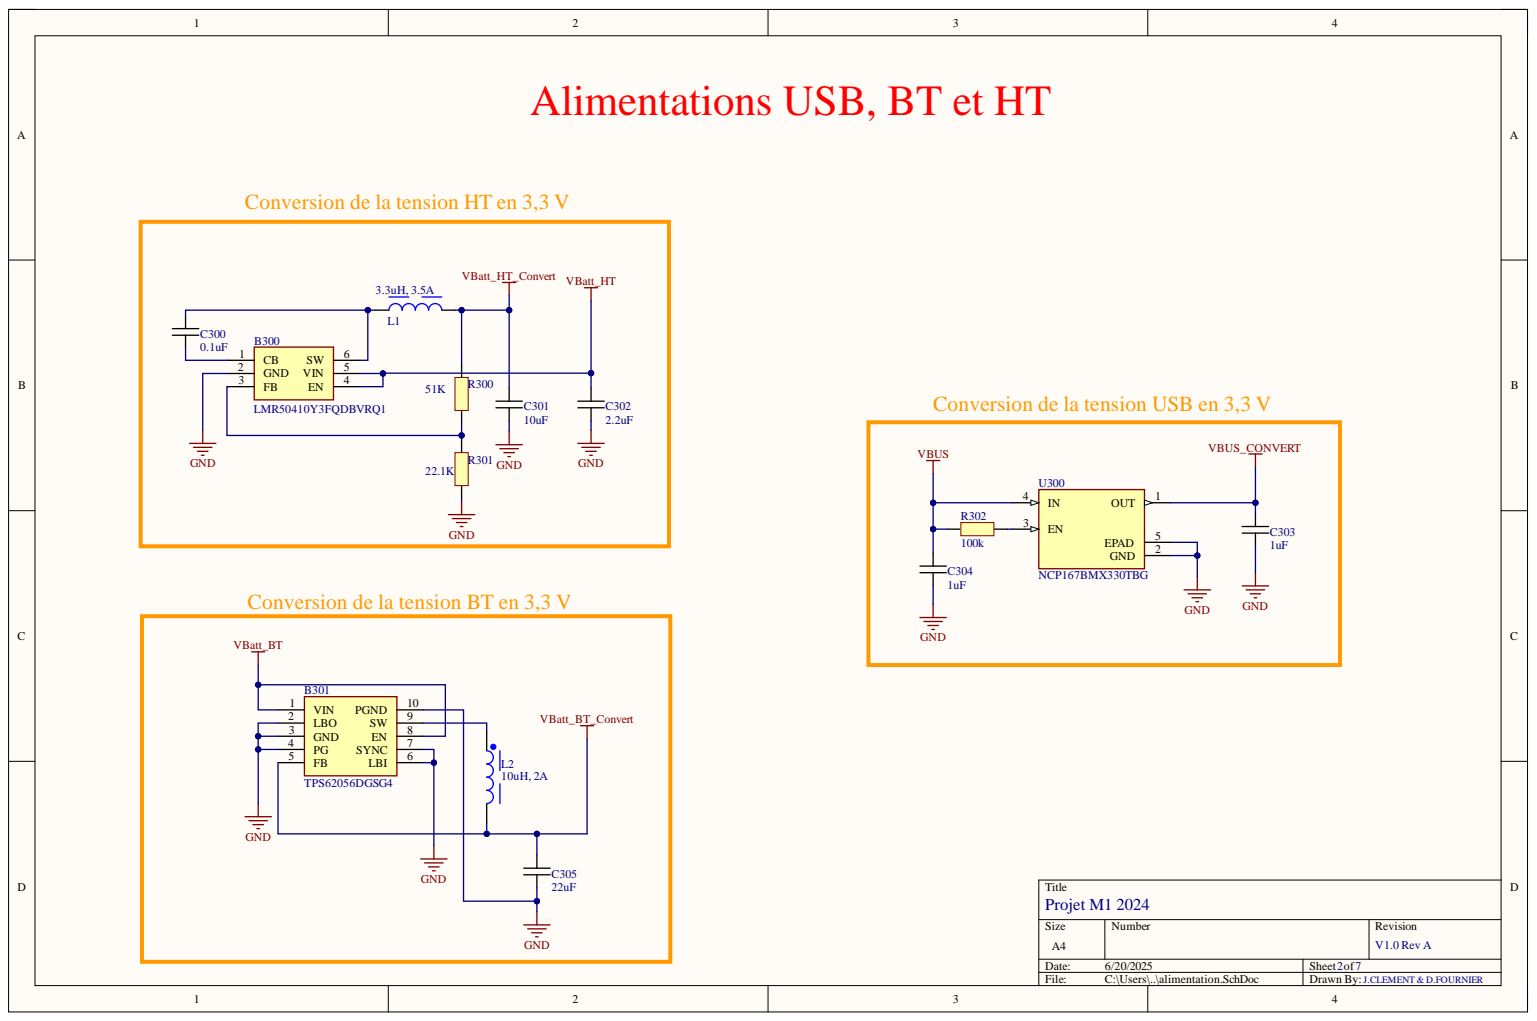
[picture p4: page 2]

Alimentations USB, BT et HT VBatt_HT

3 | | 4 | R3 0 0
FB E N

FB LBI | | 1 0 u H, | 2 A

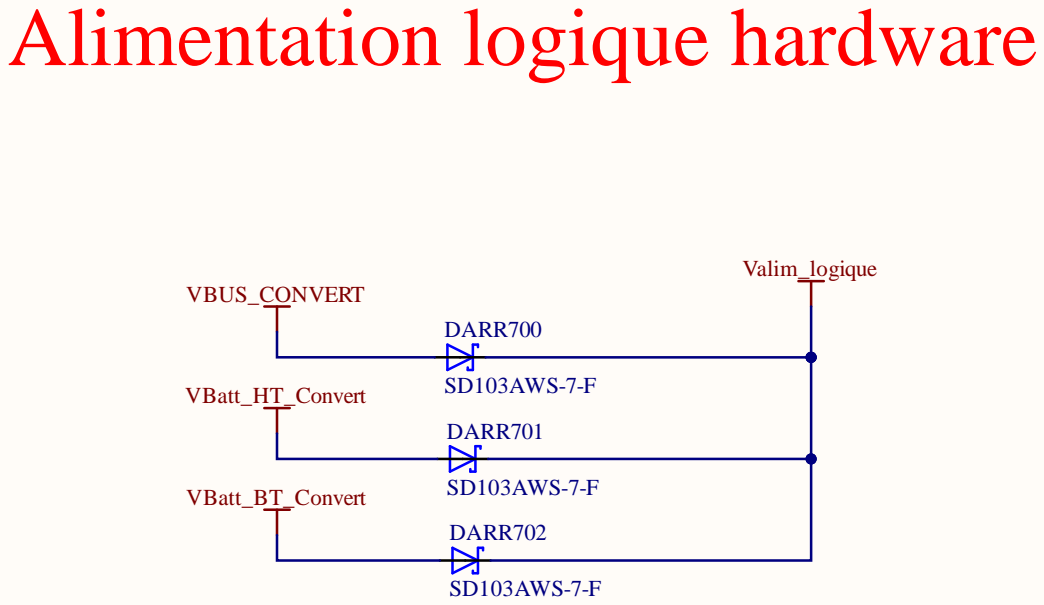
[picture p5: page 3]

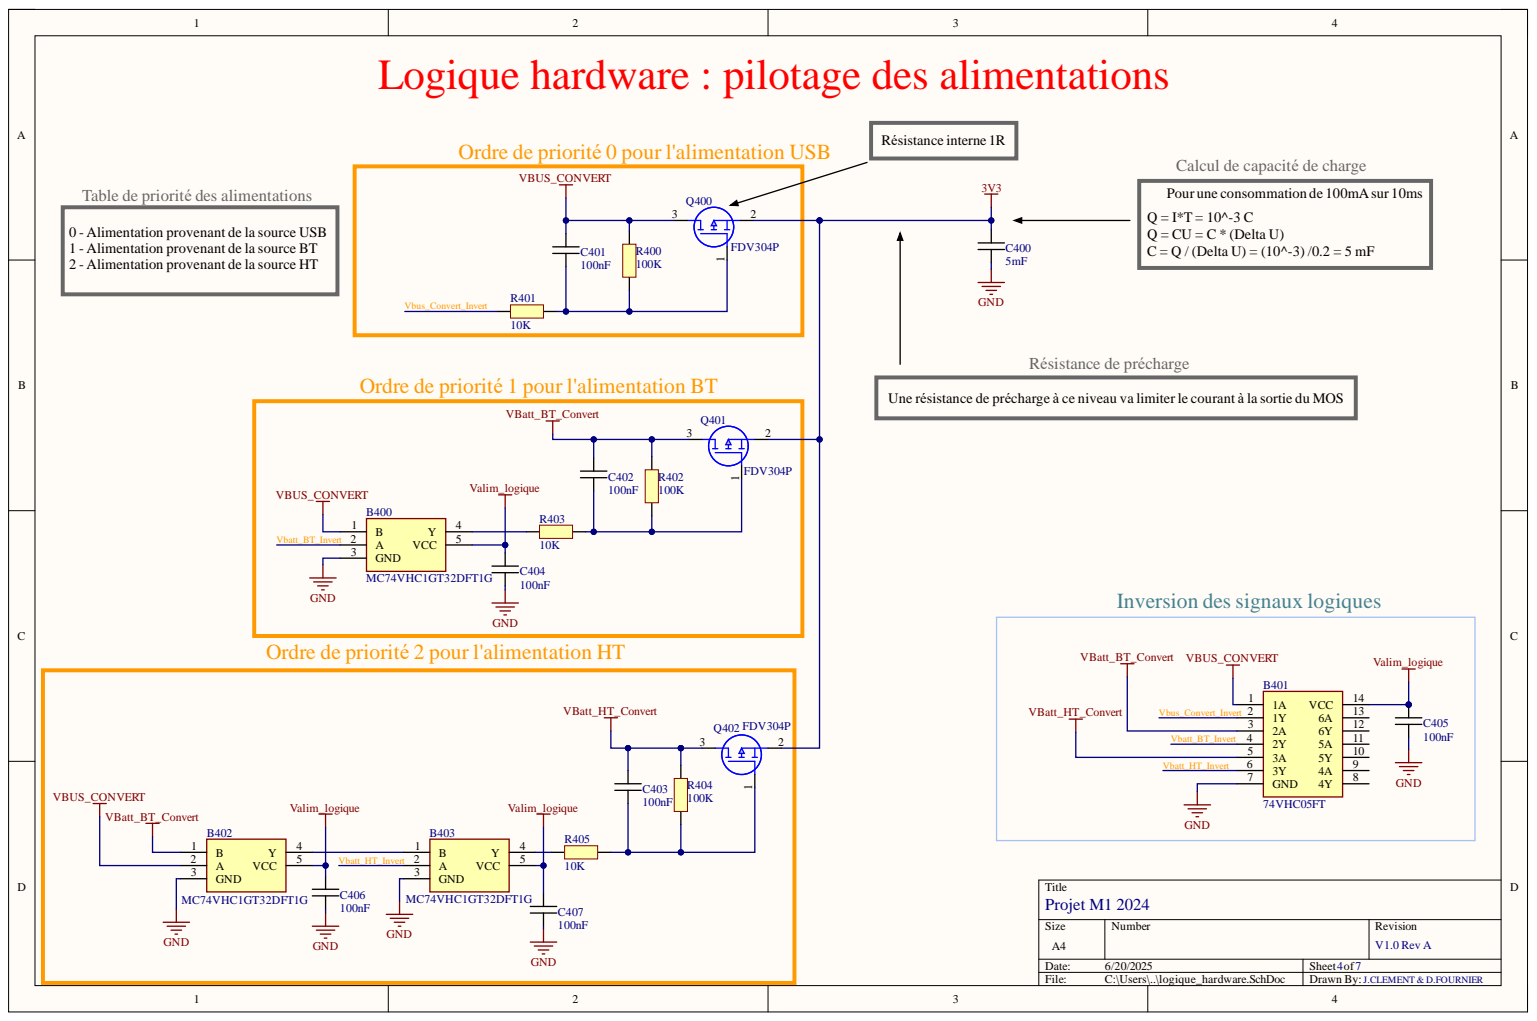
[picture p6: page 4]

Logique hardware : pilotage des alimentations

Ordre de priorité 0 pour l'alimentation USB

Calcul de capacité de charge

Table de priorité des alimentations

Pour une consommation de 100mAsur 10ms
Q = CU = C * (Delta U)
C = Q / (Delta U) = (10^-3) /0.2 = 5 mF

0 - Alimentation provenant de la source USB
1 - Alimentation provenant de la source BT
2 - Alimentation provenant de la source HT

Ordre de priorité 1 pour l'alimentation BT

Une résistance de précharge à ce niveau va limiter le courant à la sortie du MOS

Ordre de priorité 2 pour l'alimentation HT

A 2 | Vbatt_HT_Invert | A 2
GND 3 | | GND 3

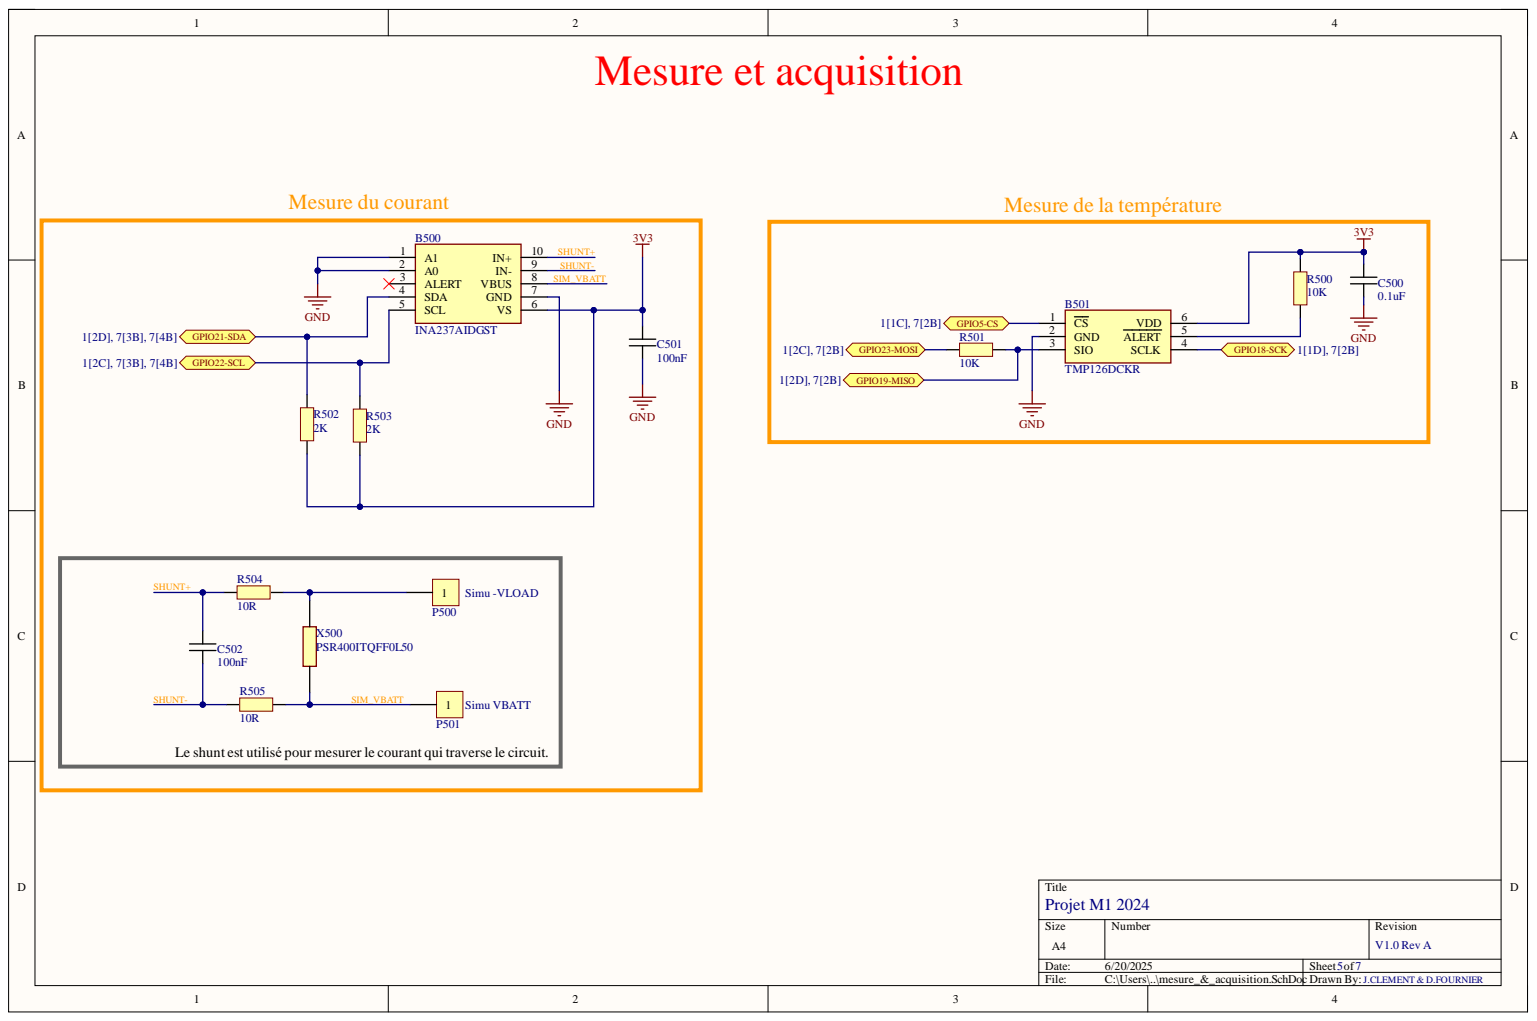
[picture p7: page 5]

2 | 9 | SHUNT -ATT
3 | | 8 7 | S I M_VB

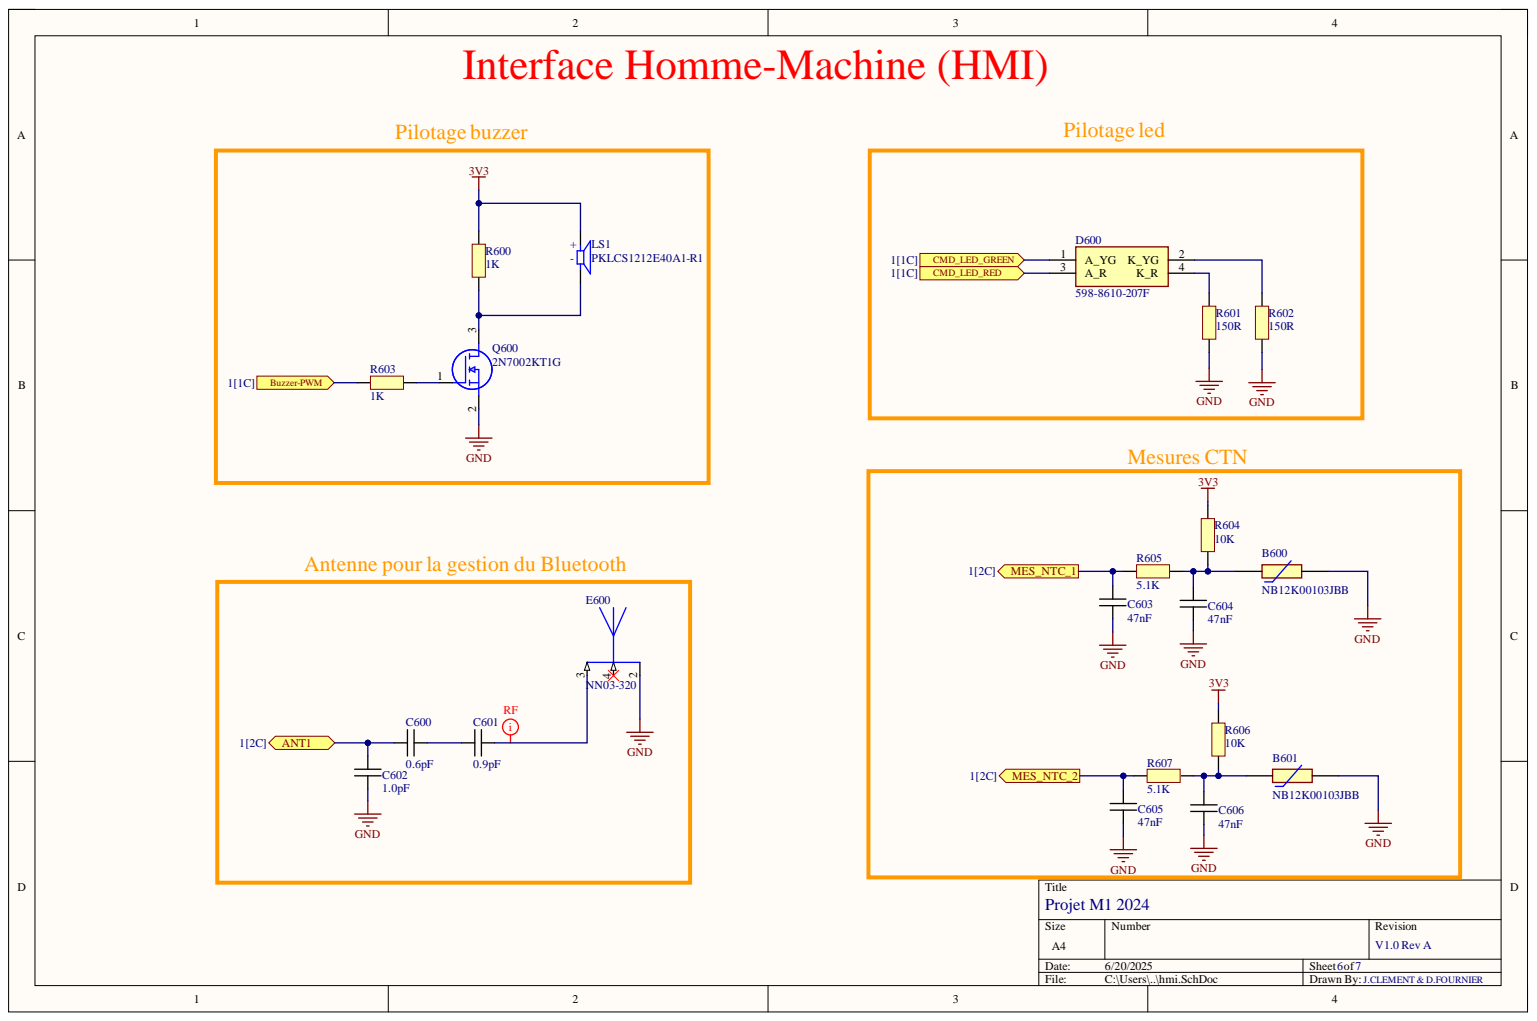
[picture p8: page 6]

Interface Homme-Machine (HMI)

Antenne pour la gestion du Bluetooth

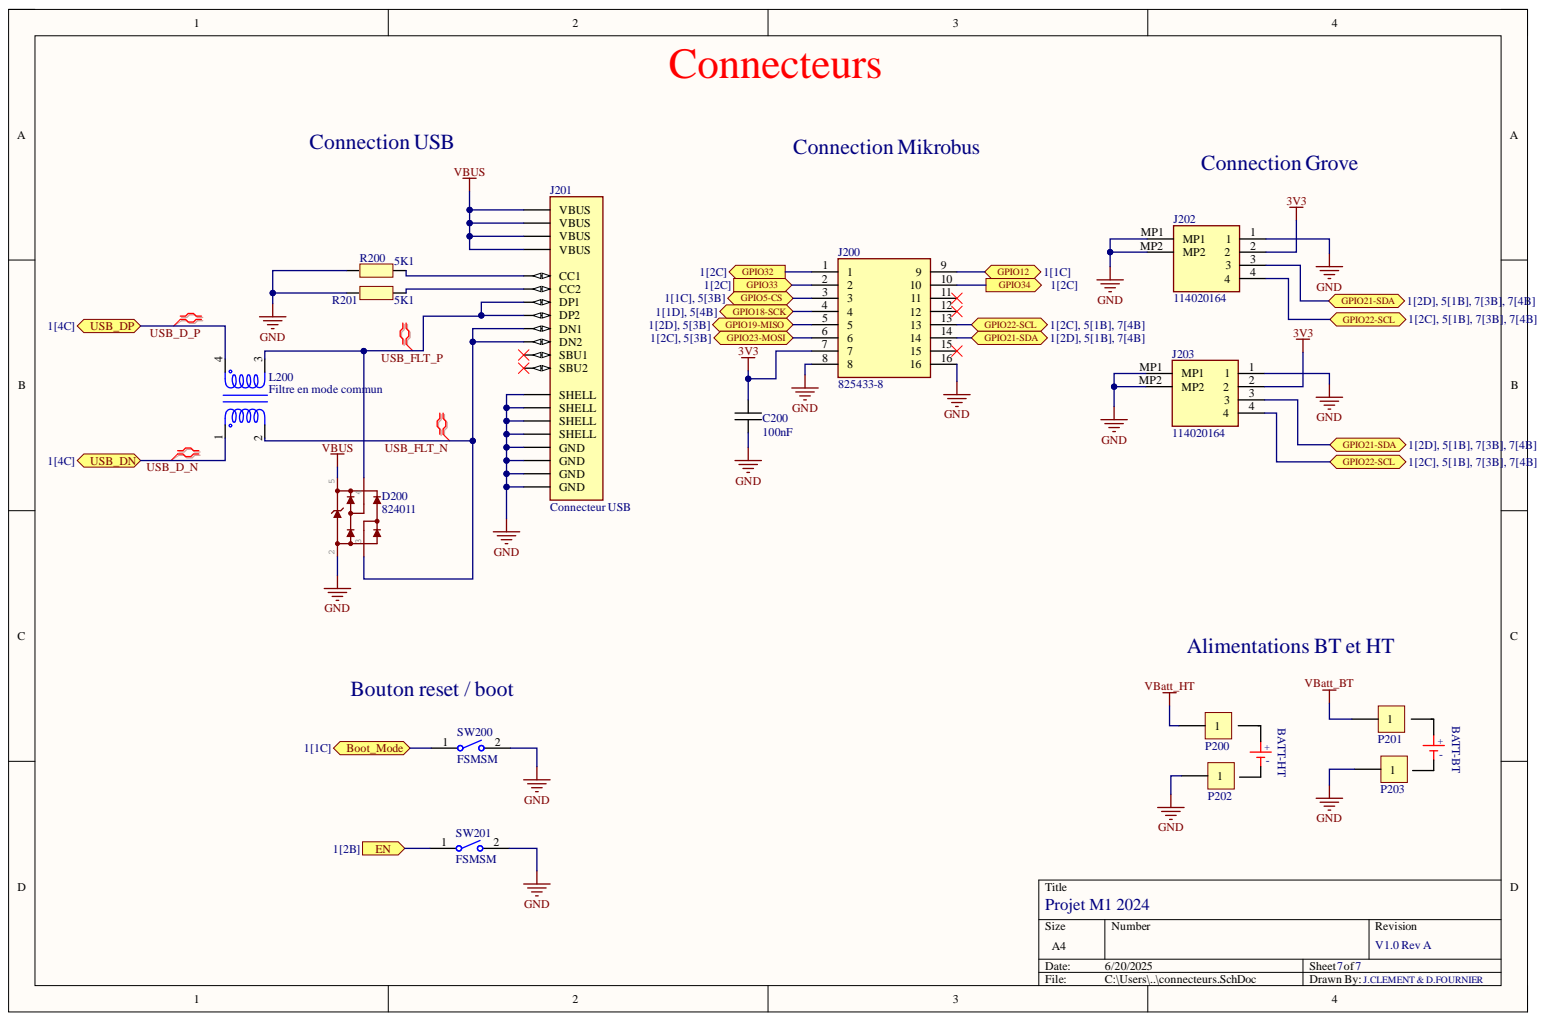
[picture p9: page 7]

Filtre en mode commun

Alimentations BT et HT

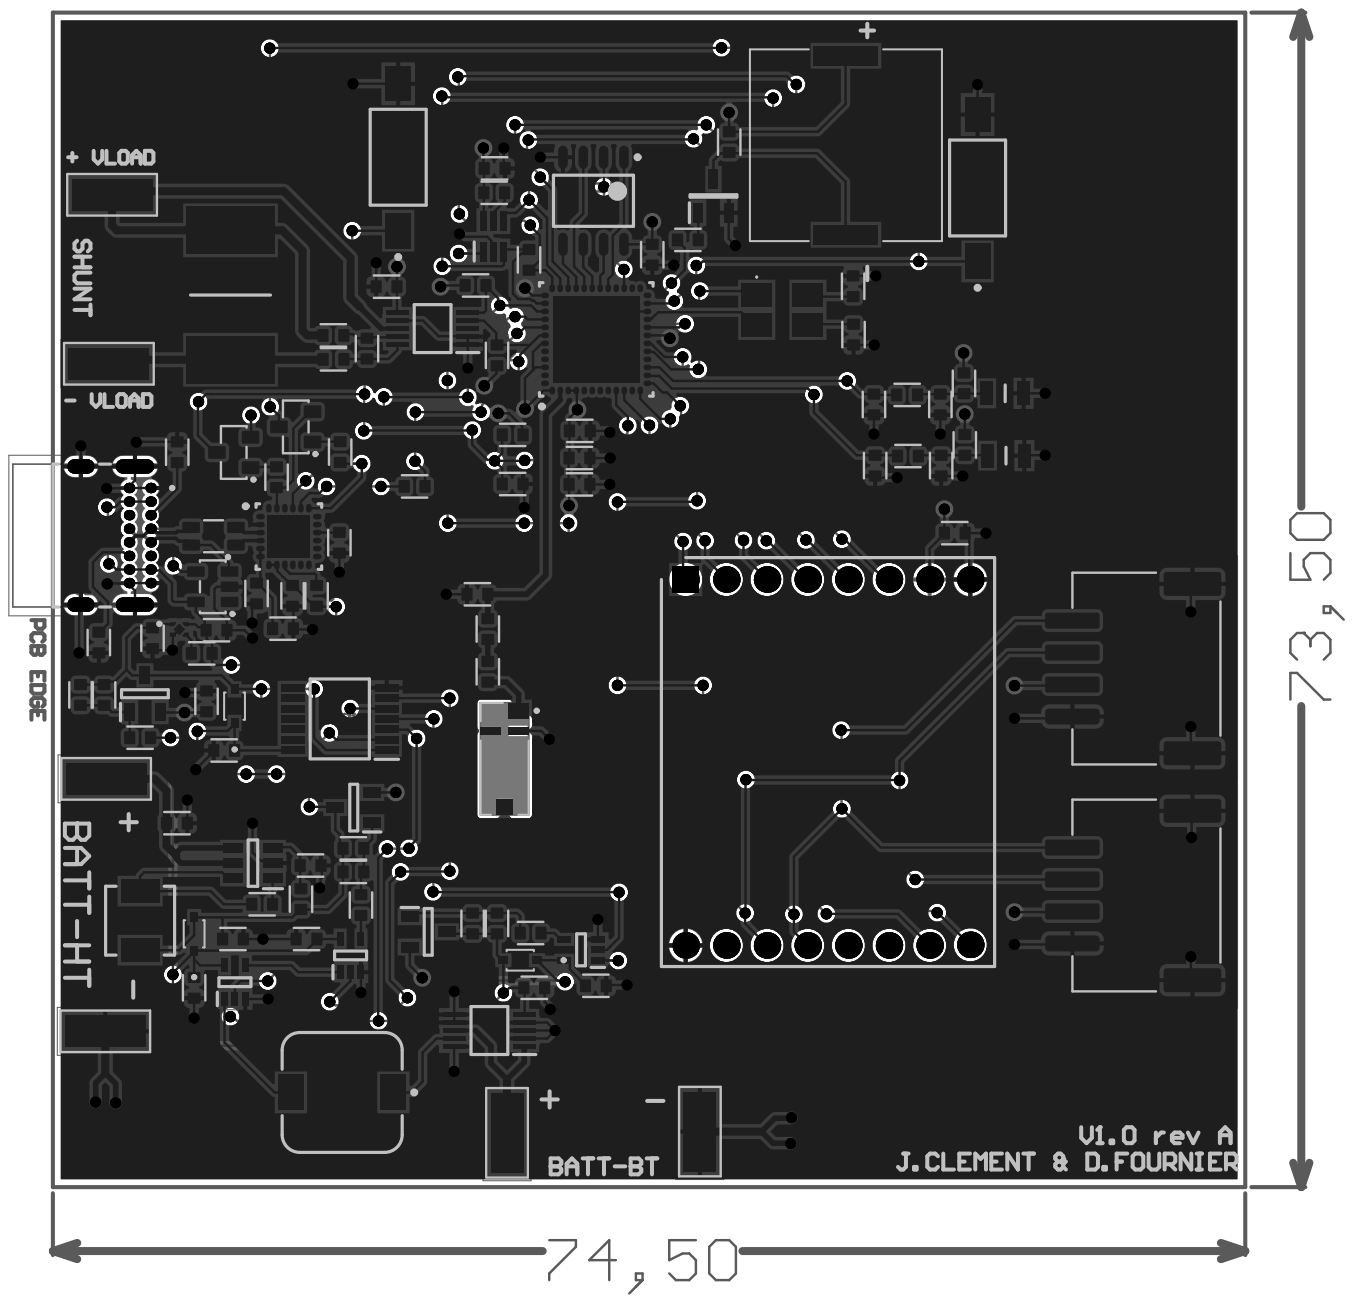
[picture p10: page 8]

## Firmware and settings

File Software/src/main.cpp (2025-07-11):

#include <Arduino.h>
#include "config.hpp"
#include "constants.hpp"
#include "led.hpp"
#include "buzzer.hpp"
#include "ina237.hpp"
#include "tmp126.hpp"
#include "ntc_board.hpp"
#include "i2cScanner.hpp"
#include "SPIFFS.h"
#include "FS.h"
#include "ble.hpp"

LED* _ledGreen;
LED* _ledRed;
BUZZER* _buzzer;
NTC_Board* _ntc1;
NTC_Board* _ntc2;
TMP126 _tmpsensor(PIN_TMP126_CS);
INA237 _ina237(INA237_ADDR);
I2C_SCANNER i2cScanner;
BLE* _ble;

// functions
bool initialize();
String getTimestamp();
CommandType stringToCommand(String cmd);
const char* logTypeToString(LogType type);
bool writeLogSPIFFS(LogType logType, String message);
bool readLogSPIFFS(void);

class ServerCallbacks : public BLEServerCallbacks {
    void onConnect(BLEServer* pServer) override {
        Serial.println("✅ Client connecté");
    }

    void onDisconnect(BLEServer* pServer) override {
        Serial.println("🔌 Client déconnecté, redémarrage de l'advertising");
        BLEDevice::startAdvertising();
    }
};

class BLECallbacks : public BLECharacteristicCallbacks {
    void onWrite(BLECharacteristic *pCharacteristic) override {
        String value = pCharacteristic->getValue().c_str();
        Serial.print("Received BLE data: ");
        Serial.println(value);

        switch (stringToCommand(value)) {
            case CommandType::BUZZER:
                if (_buzzer) _buzzer->BUZZER_launchTest();
                _ble->BLE_sendAck(value);
                break;

            case CommandType::LED_R:
                if (_ledRed) _ledRed->LED_launchTest();
                _ble->BLE_sendAck(value);
                break;

            case CommandType::LED_G:
                if (_ledGreen) _ledGreen->LED_launchTest();
                _ble->BLE_sendAck(value);
                break;

            case CommandType::CTN:
                if (_ntc1) _ble->BLE_sendAck(String(_ntc1->NTC_launchTest()));
                if (_ntc2) _ble->BLE_sendAck(String(_ntc2->NTC_launchTest()));
                break;

            case CommandType::I2C:
                _ble->BLE_sendAck(i2cScanner.I2C_SCANNER_launchTest());
                break;

            case CommandType::INA:
                _ina237.INA237_launchTest();
                break;

            case CommandType::TEMP:
                _ble->BLE_sendAck(String(_tmpsensor.TMP126_launchTest()));
                break;

            case CommandType::R_LOG:
                if (!readLogSPIFFS()) {
                    Serial.println("❌ Error during test for R_LOG");
                }
                break;

            case CommandType::W_LOG:
                if (!writeLogSPIFFS(LOG_INFO, "Log from BLE !")) {
                    Serial.println("❌ Error during test for W_LOG");
                }
                break;

            case CommandType::UNKNOWN:
            default:
                Serial.println("❓ Unknown BLE command");
                break;
        }
    }
};

void setup() {
    if(initialize()) {
        Serial.println("Initialize done !");
    } else {
        Serial.println("❌ Error during intialize !");
    }
}

void loop() {   
}

// Init
bool initialize() {
    Serial.begin(SERIAL_MONITOR_SPEED_115K);
    Serial.println("Initialize ...");

    if (!SPIFFS.begin(true)) {
        Serial.println("❌ [initialize] SPIFFS Error !");
        return false;
    } else {
        Serial.println("[initialize] SPIFFS : ✅");
    }

    _ledGreen = new LED(PIN_LED_GREEN);
    _ledRed = new LED(PIN_LED_RED);
    Serial.println("[initialize] LEDs   : ✅");

    _buzzer = new BUZZER(PIN_BUZZER);
    Serial.println("[initialize] Buzzer : ✅");

    _tmpsensor.TMP126_begin();
    Serial.println("[initialize] NTC1   : ✅");

    _ntc1 = new NTC_Board(PIN_NTC1);
    Serial.println("[initialize] NTC1   : ✅");

    _ntc2 = new NTC_Board(PIN_NTC2);
    Serial.println("[initialize] NTC2   : ✅");

    analogReadResolution(12);
    if (!_ina237.INA237_begin()) {
        Serial.println("❌ [initialize] Init error for INA237 !");
        while (true);  
    } else {
        Serial.println("[initialize] INA237 : ✅");
    }
   
    // BLE
    _ble = new BLE(new ServerCallbacks(), new BLECallbacks());

    return true;
}

// Commands
CommandType stringToCommand(String cmd) {
    if (cmd == "BUZZER") return CommandType::BUZZER;
    if (cmd == "LED_R")  return CommandType::LED_R;
    if (cmd == "LED_G")  return CommandType::LED_G;
    if (cmd == "CTN")    return CommandType::CTN;
    if (cmd == "I2C")    return CommandType::I2C;
    if (cmd == "INA")    return CommandType::INA;
    if (cmd == "TEMP")   return CommandType::TEMP;
    if (cmd == "R_LOG")  return CommandType::R_LOG;
    if (cmd == "W_LOG")  return CommandType::W_LOG;
    return CommandType::UNKNOWN;
}

// Log 
// TODO create SPIFF driver into lib/SPIFFS folder
String getTimestamp() {
    unsigned long seconds = millis() / 1000;
    int hours = seconds / 3600;
    int minutes = (seconds % 3600) / 60;
    int secs = seconds % 60;

    char buffer[12];
    snprintf(buffer, sizeof(buffer), "[%02d:%02d:%02d]", hours, minutes, secs);

    return String(buffer);
}

const char* logTypeToString(LogType type) {
    switch (type) {
        case LOG_INFO: return "[INFO]";
        case LOG_WARNING: return "[WARNING]";
        case LOG_ERROR: return "[ERROR]";
        case LOG_DEBUG: return "[DEBUG]";
        case LOG_FATAL: return "[FATAL]";
        default: return "[UNKNOWN]";
    }
}

bool writeLogSPIFFS(LogType logType, String message) {
    Serial.println("------------ WRITE SPIFFS LOG ------------");
    
    File file = SPIFFS.open(LOG_FILE, FILE_APPEND);
    
    if (!file) {
        Serial.println("❌ [writeLogSPIFF] Error openning log file !");
        Serial.println("------------------------------------------");
        return false;
    }

    String log = getTimestamp() + String(logTypeToString(logType)) + " " + message;
    Serial.println("log : " + log);
    file.println(log);
    file.close();

    Serial.println("------------------------------------------");
    return true;
}

bool readLogSPIFFS(void) {
    Serial.println("------------ READ SPIFFS LOG ------------");

    File file = SPIFFS.open(LOG_FILE, FILE_READ);
    if (!file) {
        Serial.println("❌ [readLogSPIFF] Error openning log file !");
        Serial.println("-----------------------------------------");
        return false;
    }

    Serial.println("File content :");
    while (file.available()) {
        Serial.write(file.read());
    }
    file.close();

    Serial.println("-----------------------------------------");
    return true;
}

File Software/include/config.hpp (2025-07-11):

#ifndef CONFIG_HPP
#define CONFIG_HPP

// Serial monitor speed
#define SERIAL_MONITOR_SPEED_115K 115200

// INA
#define INA237_ADDR 0x40

// TMP126
#define TMP126_REG_TEMP_RESULT   0x00
#define TMP126_RESOLUTION        0.03125f

// NTC
#define PIN_NTC1 26
#define PIN_NTC2 25

// SPI
#define PIN_SPI_MOSI 23
#define PIN_SPI_MISO 19
#define PIN_SPI_SCK  18
#define PIN_TMP126_CS 5

// I2C
#define PIN_I2C_SDA 21
#define PIN_I2C_SCL 22

// BUZZER
#define PIN_BUZZER 13

// LED
#define PIN_LED_RED 15
#define PIN_LED_GREEN 14

// BLE
#define WRITE_CHARACTERISTIC "2A19"
#define NOTIFY_CHARACTERISTIC "2A20"

#endif // CONFIG_HPP
